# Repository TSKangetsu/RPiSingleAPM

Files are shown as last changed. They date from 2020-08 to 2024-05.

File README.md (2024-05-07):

# SingleFlight

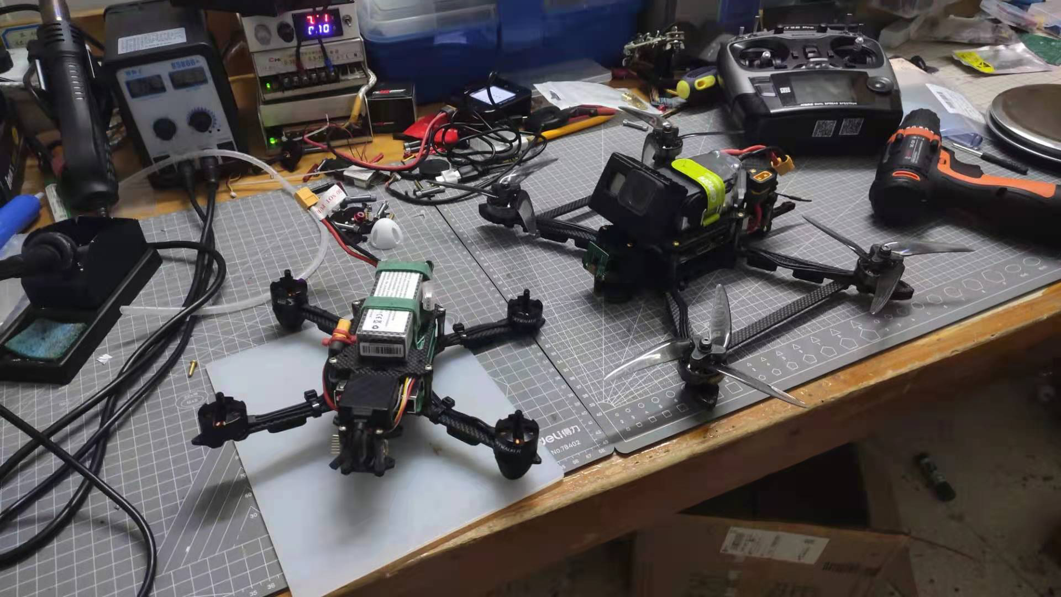
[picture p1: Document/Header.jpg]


SingleFlight is linux-userland C++ flight controller, without any external micro-controller

This project differs from Betaflight and inav in that it focuses on running controller in ARM-Linux, and suit for indoor navigation. <br/>

Warnning: This project is GPL3.0! <br/>

addon: when will it release first version? after GPS hold has done, should comming soon

## TODO: NOW trying support rockpi4b, openwrt onborad version will comming soon

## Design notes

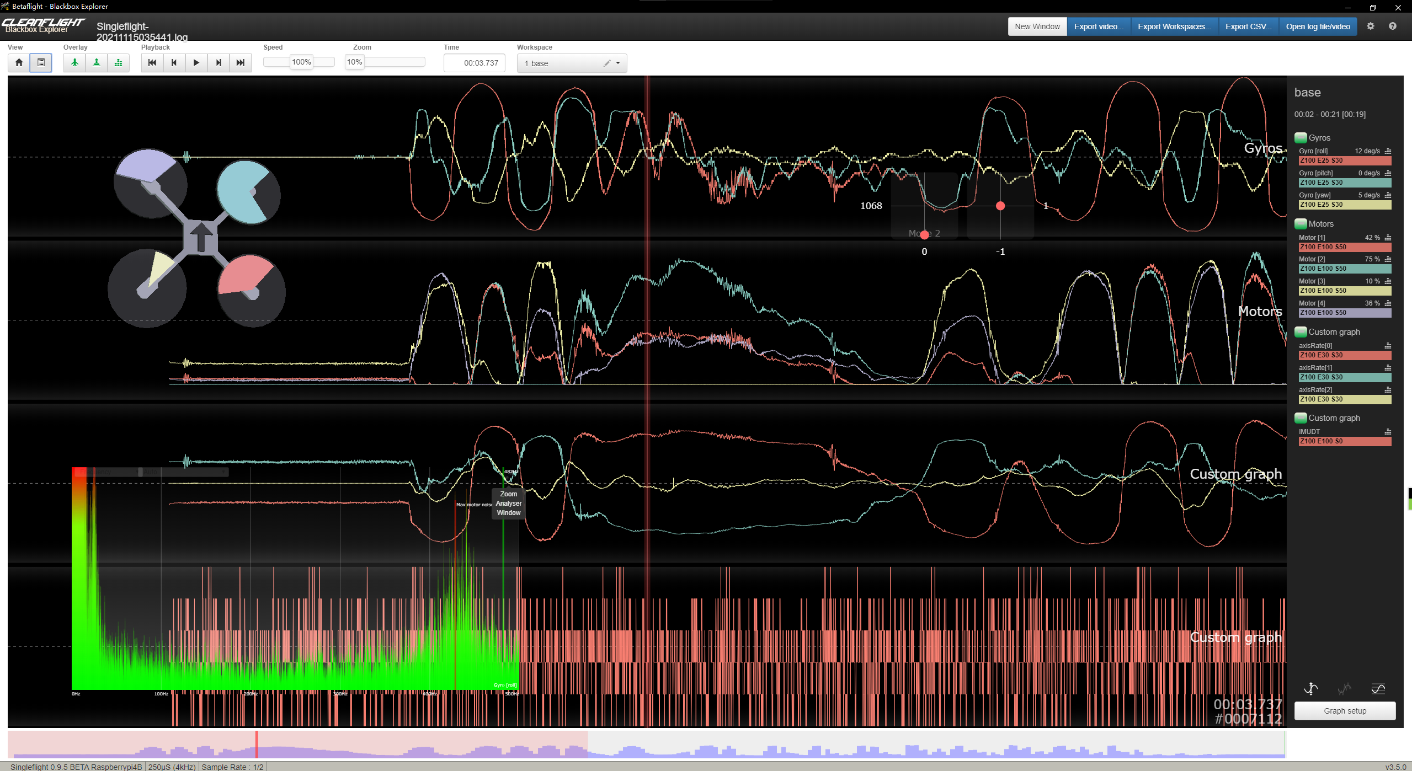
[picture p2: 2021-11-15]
Document/image.png

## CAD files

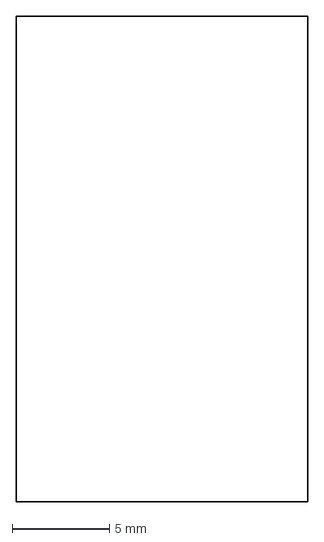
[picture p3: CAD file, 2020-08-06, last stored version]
PCB-pi/mpu9250.DXF
15.0 x 25.0 mm

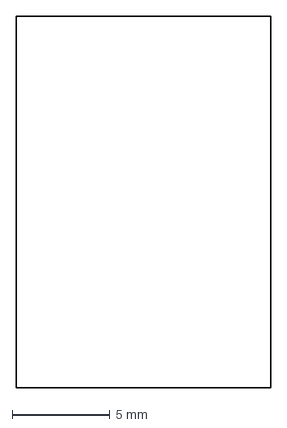
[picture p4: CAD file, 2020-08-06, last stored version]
PCB-pi/ms5611.DXF
13.0 x 19.0 mm

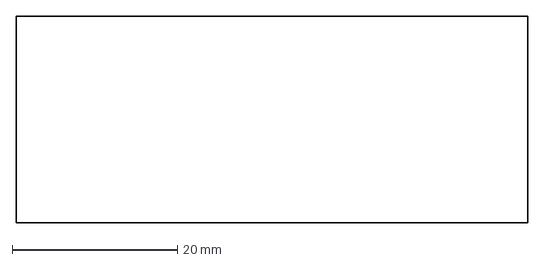
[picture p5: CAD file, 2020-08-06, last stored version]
PCB-pi/pca9685.DXF
62.0 x 25.0 mm

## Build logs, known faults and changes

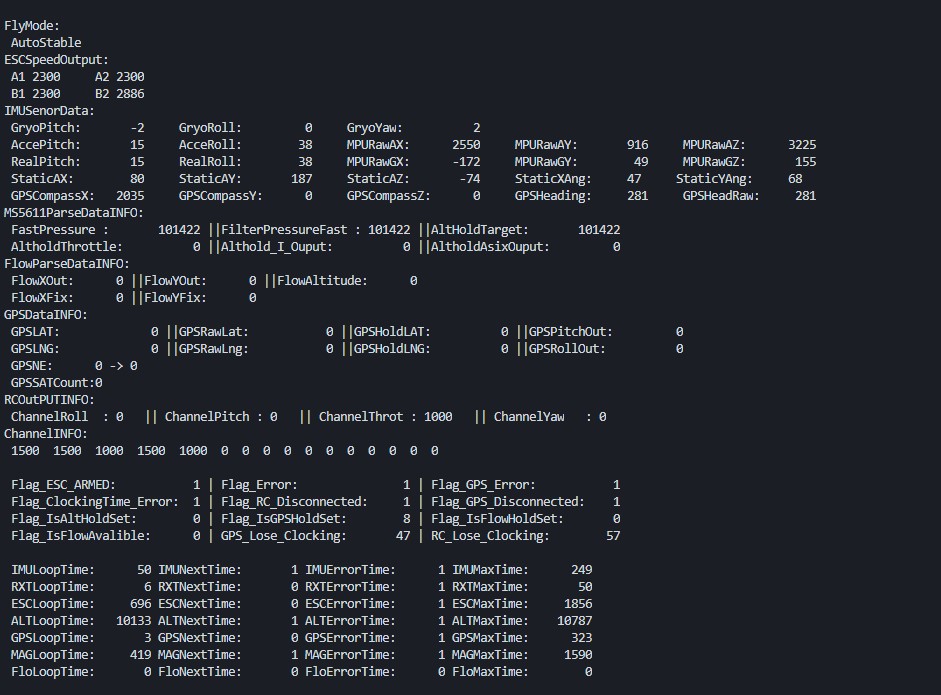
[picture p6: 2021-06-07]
Document/DebugInfo.jpg

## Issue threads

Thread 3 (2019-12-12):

Add MS5611 to support Althold Mode

TSKangetsu, 2019-12-12:

TSKangetsu, 2020-07-15:
alt fix should be add at  RF._uORB_RC_Out_Throttle , In progress

TSKangetsu, 2020-09-18:
Need test, on 9/20

TSKangetsu, 2020-10-27:
increase althold rate fresh from 50hz to 100hz

TSKangetsu, 2020-10-28:
at 100hz althold works well , testing pass

TSKangetsu, 2020-10-30:
hover throttle unstable need to fix

TSKangetsu, 2020-10-31:
may need accel to get climbeRate , bug accel data can't trusted

TSKangetsu, 2020-10-31:
4s throttle and 3s throttle are different , I meet some throuble

TSKangetsu, 2020-11-03:
can't use ms5611 to caculate hover throttle,should input hover throttle by manual

TSKangetsu, 2021-02-05:
will use vertical speed pid , this thread also at
https://github.com/TSKangetsu/RPiSingleAPM/issues/46

Closed 2021-04-05.

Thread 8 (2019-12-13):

FailedSafe landing support

TSKangetsu, 2019-12-13:

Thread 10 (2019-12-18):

improve timming clock detect

TSKangetsu, 2019-12-18:
Do not use timer out side , include timer at safycheck()

TSKangetsu, 2020-09-26:
SPI on new raspbain went error , with unstable latency
with https://github.com/raspberrypi/linux/issues/2094

solve: core_freq=250 (force_turbo=1) still on investigating

TSKangetsu, 2020-09-26:
and core_freq=250 to /boot/config.txt can solve , add to readme

TSKangetsu, 2021-02-04:
spi speed was up to 1mb/s , problem could not refound, closed

TSKangetsu, 2021-08-02:
this is a hardware issues because of the low voltage to raspberrypi

TSKangetsu, 2021-08-03:
dt is error with a little big delay , when fresh rate over 2khz, madgwick error become to big

TSKangetsu, 2021-08-04:
check here
https://stackoverflow.com/questions/54620641/why-nanosleep-adds-a-constant-delay-and-how-can-i-avoid-that
slove by time-50us

TSKangetsu, 2021-12-15:
https://github.com/TSKangetsu/RPiSingleAPM/commit/1f509caf203f00de5ce3eb194611f432136c3439

getimeofday is depend on systime but system clock, network time update cause some random issues, real dangerous

Closed 2021-12-15.

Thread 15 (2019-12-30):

Ibus Bug fix

TSKangetsu, 2019-12-30:
remove wiringPiSerial , using terminos

Closed 2019-12-31.

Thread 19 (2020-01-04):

Crashing on Raspberry3B+

TSKangetsu, 2020-01-04:
It seem like a time delay error

TSKangetsu, 2020-01-06:
control read time too long , delay error

TSKangetsu, 2020-01-06:
problem found: unsigned int force to int cost some problem , will fix up next version

Closed 2020-01-06.

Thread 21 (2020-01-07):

improve gryo filter

TSKangetsu, 2020-01-07:

TSKangetsu, 2021-05-12:
plan to use pt1? or biquad filter ,or dynamic

TSKangetsu, 2021-06-03:
current gryo filter is stable enough at  5'' to 7'' quad , close it temporary

Closed 2021-06-03.

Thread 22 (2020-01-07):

add kalman filter

TSKangetsu, 2020-01-07:
add at develop , but could test

TSKangetsu, 2020-10-15:
kalman filter is not to be used, do not works well

TSKangetsu, 2021-03-17:
kaman was add to 6219fcba6c9ecfa01a249ae43ae32336d2badb27
thanks https://github.com/simondlevy/TinyEKF/

TSKangetsu, 2021-04-05:
TinyEKF was used  in  navigation now

Closed 2021-04-05.

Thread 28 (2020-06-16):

Sensor Data correct checking System add

TSKangetsu, 2020-06-16:
check the sensor is working correct

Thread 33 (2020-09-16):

Task system add

TSKangetsu, 2020-09-16:
add task system for prevent gyro error

Closed 2020-09-26.

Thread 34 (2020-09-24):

Raspberrypi4 more 4 uart support

TSKangetsu, 2020-09-24:

TSKangetsu, 2020-09-24:
Raspberrypi4 has more uart port:
uart0   14  15              8   10
uart1   14  15              8   10
uart2   0   1   2   3       27  28  (I2C)
uart3   4   5   6   7       7   29
uart4   8   9   10  11      24  23  (SPI0)
uart5   12  13  14  15      32  33  (gpio-fan)

uart 1,3,5 will be using for pmw3901 and gps

TSKangetsu, 2020-09-24:
Redesigned PCB extend board:

TSKangetsu, 2020-09-24:
move pcb board i2c-0 to i2c-1 for uart2 , SDA0 , SCL0 is use for uart, i2c sensor go from sda1 and scl1

Closed 2021-11-11.

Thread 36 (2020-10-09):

Compass support

TSKangetsu, 2020-10-09:

TSKangetsu, 2020-10-09:
support MPU9250 compass and M8N compass

TSKangetsu, 2020-10-11:
用中文吐槽：
    根本搞不定，I2C状态的mpu9250还好说，把mpu9250作为主机读取9250的磁力计太过恶心，响应极慢，状态完全不可知，可能会抛弃spi模式的mpu9250板载磁力计

TSKangetsu, 2020-10-12:
在 https://github.com/TSKangetsu/RPiSingleAPM/commit/e544b20a4bf567b559938b5c271917177a4f9de5 中解决

TSKangetsu, 2020-11-06:
mpu9250的电子罗盘在gpio5V供电时几乎不可用，将优先对gps罗盘提供支持

TSKangetsu, 2020-11-12:
QMC5883L support complete

TSKangetsu, 2021-11-18:
compass now support base angle asix , it works fine, but i want to use AHRS.....

TSKangetsu, 2021-11-19:
AHRS support complete,

Now ignore compass input AHRS when mag is being influence by eletronic

TSKangetsu, 2021-12-20:
should support HMC5883

TSKangetsu, 2021-12-20:
HMC5883L is great! very stable and correct ,fuck QMC5883, everytime QMC5883 boot must calibrated

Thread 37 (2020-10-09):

GPS M8N Support

TSKangetsu, 2020-10-09:

TSKangetsu, 2020-11-08:
gps reading terrible delay over 6s , debuging

TSKangetsu, 2020-11-08:
这并不是一个延迟的问题，而是gps输出没有给进pid闭环导致pid与gps对抗

TSKangetsu, 2020-11-12:
GPS angle caculate error fixed

https://github.com/TSKangetsu/RPiSingleAPM/commit/5803b03a980b3fd887e40f29bbde1c3bb217cbd5

TSKangetsu, 2020-11-20:
GPS delay time is depending when serial port is being opened, if serial port is opened and free for 5sec , the data time line also  delay 5sec  , WTF???
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

TSKangetsu, 2021-11-08:
this plan is pushing for a long time...
wait for the GPS kit and will develop soon...

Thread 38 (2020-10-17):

Using fixed pwm value instead of rc pwm

TSKangetsu, 2020-10-17:

Closed 2024-05-07.

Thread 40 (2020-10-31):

New Loging System add

TSKangetsu, 2020-10-31:
log pid output ,accel gryo ,altitude info for survey

TSKangetsu, 2021-08-16:
same to
https://github.com/TSKangetsu/RPiSingleAPM/issues/60

close

Closed 2021-08-16.

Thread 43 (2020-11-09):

roll pitch throttle fixed up

TSKangetsu, 2020-11-09:

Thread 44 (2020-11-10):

Unexpected Accel data ouput

TSKangetsu, 2020-11-10:

TSKangetsu, 2020-11-10:
this bug also cause compass error
https://github.com/TSKangetsu/RPiSingleAPM/issues/36

TSKangetsu, 2020-11-10:
it seems to be a hardware problem , try to add accel xyz calibration

TSKangetsu, 2020-11-10:
the testing quadcopter's mpu accel z output is 2100 away from center , this is an hardware error

TSKangetsu, 2020-11-11:
add accel calibration at https://github.com/TSKangetsu/RPiSingleAPM/commit/472f2326f5d2c099a423c9d3b051ebbac80c45c1

using SingleAPM -a to calibrate accel

Closed 2020-11-11.

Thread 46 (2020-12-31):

Accel movement detection

TSKangetsu, 2020-12-31:

TSKangetsu, 2021-02-04:
was done at https://github.com/TSKangetsu/RaspberryPiMPU/commit/2f9b78fb7e9962127a78856a36eaf97fbc136a7f

TSKangetsu, 2021-04-05:
now ,it fully support with 10hz flow and accel movement detection, configuration!!!!!

TSKangetsu, 2021-05-04:
accel on z with pressure is unstable , try using Accel PID controller instead Speed control,
Posistion * P -> Speed * P2 -> Accel * PID

TSKangetsu, 2021-05-09:
accel work able now , but easy to influence cause by vibration

TSKangetsu, 2021-05-09:
plan to add vibration detect dynamic change accel beta? I don't kown.....  just try

TSKangetsu, 2021-05-09:
same issues like this
https://github.com/iNavFlight/inav/issues/486

TSKangetsu, 2021-05-12:
using 5hz throttle LPF make baro altitude hold is stable now
switch to horizontal movement detect

TSKangetsu, 2021-05-12:
althold problem is not cause by accel vibration,  barometer is bumping , so throttle is keep little move, 5hz sulove perfect

TSKangetsu, 2021-05-26:
vibration detect support

TSKangetsu, 2021-06-11:
imu attitude convert accel became terriaful when accel trust gain higher

TSKangetsu, 2021-06-12:
rotation matrix base accel deal support now , just need a stable attitude feedback

TSKangetsu, 2021-08-13:
Because of the vibration , even on ground disarm , speed reference also change crazy , still found some way to deal

TSKangetsu, 2021-08-14:
biqaud  lpf at low sample rate won't work well, Sample rate at lease >500hz ,

TSKangetsu, 2021-08-14:
mpu6000 DLPF's Gyro and accel is bound, but mpu9250 are separated, so directly set 44hz hardware lpf for mpu9250 is well?..
still need test

TSKangetsu, 2021-08-14:
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

TSKangetsu, 2021-08-14:
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

TSKangetsu, 2022-10-26:
now I know: INAV is using Speed-base PID controller , NOT ACCELRATION-BASE, should fallback navigation PID to Speed

TSKangetsu, 2022-10-26:
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

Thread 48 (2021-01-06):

GRYO: pitch and roll is not correct when yaw change

TSKangetsu, 2021-01-06:

TSKangetsu, 2021-01-06:
fix at Master https://github.com/TSKangetsu/RPiSingleAPM/commit/70311a7940c91641bba5ec6a41bac298fa3beb66
and
ad dev  https://github.com/TSKangetsu/RPiSingleAPM/commit/66b56c99425fcdebfa19f5bab78698124eaafdec

Closed 2021-01-06.

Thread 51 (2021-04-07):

Position hold Brake support

TSKangetsu, 2021-04-07:

TSKangetsu, 2021-06-09:
Speed braking seen not right when copter fast bark, will cause flow output unstable

TSKangetsu, 2021-06-09:
flow move output also not seems well when only x or only y change , will cause other movement

TSKangetsu, 2021-06-09:
like a imu accel problem
https://github.com/TSKangetsu/RPiSingleAPM/issues/68

Closed 2021-06-12.

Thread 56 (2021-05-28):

Unstable yaw controller

TSKangetsu, 2021-05-28:

TSKangetsu, 2021-05-28:
PID Yaw's controller problem ,fast span will cause pitch and roll jumping , may a  mixer  problem

TSKangetsu, 2021-05-29:
this is not a mixer problem, mixer is correct , Yaw PID's I logic should be reconsider

TSKangetsu, 2021-05-29:
a health and strong PID settings can prevent fast Yaw change cause pitch and roll I-Gain jump

TSKangetsu, 2021-05-29:
INAV seems to take a lot limit on I-Term controller , this issues may delay

TSKangetsu, 2021-05-29:
This issues will move to
https://github.com/TSKangetsu/RPiSingleAPM/issues/58

TSKangetsu, 2021-05-30:
this not a I gain Problem , even the I gain is zero , quad still jumping

TSKangetsu, 2021-05-31:
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
this is a mixer to caculate problem?

TSKangetsu, 2021-05-31:
mixer output was block at 2600? Unkown problems

TSKangetsu, 2021-06-01:
This issues is cause by over throttle cutoff asix，now fix

Closed 2021-06-01.

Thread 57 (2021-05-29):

Better I Term and D Term filter add

TSKangetsu, 2021-05-29:

TSKangetsu, 2021-06-02:
same to
https://github.com/TSKangetsu/RPiSingleAPM/issues/57

TSKangetsu, 2021-06-02:
double D gain filter is require

Closed 2021-06-04.

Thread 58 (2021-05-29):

Better I-Term controller

TSKangetsu, 2021-05-29:

TSKangetsu, 2021-05-29:
inav is using two tips to limit PID-I output,
1.motor mixer feedback I gain to slow down I value up
2.If motor Mixer is over throttle , set the limit when I value is reach the line

Closed 2021-06-02.

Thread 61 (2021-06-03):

Althold problems when re-arm

TSKangetsu, 2021-06-03:
when althold langding and arm , and then re-enable althold , copter will drop

TSKangetsu, 2021-06-03:
This issues may cause by accel asix math problem

TSKangetsu, 2021-06-04:
cause by  sqrt -1 in mpudata

Closed 2021-06-04.

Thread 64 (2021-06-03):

Gryo Temperature fix and high DPS support

TSKangetsu, 2021-06-03:

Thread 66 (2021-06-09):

Dynamic position Hold pid support

TSKangetsu, 2021-06-09:

TSKangetsu, 2021-06-09:
like a imu accel problem
https://github.com/TSKangetsu/RPiSingleAPM/issues/68

Closed 2021-06-09.

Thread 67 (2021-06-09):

flow position control problem

TSKangetsu, 2021-06-09:

TSKangetsu, 2021-06-09:
like a imu accel problem
https://github.com/TSKangetsu/RPiSingleAPM/issues/68

Closed 2021-06-12.

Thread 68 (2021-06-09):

IMU accel Convert unstable

TSKangetsu, 2021-06-09:

TSKangetsu, 2021-06-09:
cause by https://github.com/TSKangetsu/RPiSingleAPM/issues/69

TSKangetsu, 2021-06-09:
导致惯导不稳定的主要因素：
1.陀螺仪姿态不够准确
2.姿态补偿加速度算法存在较大问题

Closed 2021-06-12.

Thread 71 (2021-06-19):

addon notch filter require

TSKangetsu, 2021-06-19:
5inch copter will have some unexpected vibration at 100hz, when gryo total filter is 250hz , should deal with notch filter

TSKangetsu, 2021-06-20:
Don't use double notch, will cause a lot delay.
Single one works very well

TSKangetsu, 2021-06-20:
will support dynamic notch in times

Closed 2021-07-20.

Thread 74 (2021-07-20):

hardware lpf question

TSKangetsu, 2021-07-20:

TSKangetsu, 2021-07-25:
In fact, MPU module is set to 42hz hardware lpf and output speed only 1000khz, and using any clean flight filter is useless , and 42hz lpf cause a very high delay, and require a horrible high d gain

TSKangetsu, 2021-07-25:
now i set correctly with 250hz lpf ，7 inch copter fly horrible stable.

TSKangetsu, 2021-07-25:
also notice the accel hardware lpf , should not be too low

Closed 2021-07-25.

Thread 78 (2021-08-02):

raspberry pi low voltage issues

TSKangetsu, 2021-08-02:
low voltage cause tons of problem should be high notice

TSKangetsu, 2021-08-02:
same to this issues https://github.com/TSKangetsu/RPiSingleAPM/issues/10

TSKangetsu, 2021-08-02:
low voltage will cause i2c horrible unstable, SPI Clock also influence , this is most important infomation

TSKangetsu, 2021-08-02:
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
 stable 5.0v voltage error times

TSKangetsu, 2021-08-02:
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
unstable at 4.7v , error clocking horribly increase

TSKangetsu, 2021-08-02:
those result is using DMA SPI access , if in SPIDEV with userland , this will terrible

Closed 2021-08-03.

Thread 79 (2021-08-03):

Gyro temp drift improve

TSKangetsu, 2021-08-03:

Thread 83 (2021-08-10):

ALTHOLD air cushion effect detect

TSKangetsu, 2021-08-10:
using baro ground timeout and sonar

TSKangetsu, 2021-08-10:
7inch have huge air cushion influence, after take off will cause -50cm/s speed change

Closed 2021-08-13.

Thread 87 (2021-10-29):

General Linux driver support

TSKangetsu, 2021-10-29:
In Order to support Radxa or RK3399 and some arm borad

TSKangetsu, 2021-10-31:
spi has a lot driver problem in linux,
will using libmraa?

TSKangetsu, 2021-11-07:
Libmraa: meanless.

there still spidev inside ,why don't i just using spidev and  suit for driver DMA?😒

TSKangetsu, 2021-11-08:
Done

Closed 2021-11-08.

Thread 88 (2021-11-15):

Unexpected motor output

TSKangetsu, 2021-11-15:
prossibly casue by new pca9685 driver

TSKangetsu, 2021-11-15:
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
seems not a driver's bug

TSKangetsu, 2021-11-15:
this issue is cause by dt' problem
https://github.com/TSKangetsu/RPiSingleAPM/issues/89

Closed 2021-11-15.

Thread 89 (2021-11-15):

DT cause PID and motor output error

TSKangetsu, 2021-11-15:

TSKangetsu, 2021-11-15:
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

it seems to be DT cause randor error, when drop down to 2KHZ , it works fine, but 3khz or 4khz have a lot random unexpect output

TSKangetsu, 2021-11-15:
fix with dt sleep when dt overclock cause pid unexpected output
notice this because loop freq may drop a lot
https://github.com/TSKangetsu/RPiSingleAPM/commit/06b8e11d0a2dfbd81750aa7725137540e7e81584

TSKangetsu, 2021-11-15:
ok , i think i found the true reason
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

TSKangetsu, 2021-11-19:
move to https://github.com/TSKangetsu/RPiSingleAPM/issues/90

Closed 2021-11-19.

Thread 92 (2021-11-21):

Improve sensor for XY invert

TSKangetsu, 2021-11-21:

Closed 2021-12-03.

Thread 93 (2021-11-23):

Rebound pitch problem

TSKangetsu, 2021-11-23:
for comvince , after added mpu flip function, Pitch is revert from "move forward -" to "move forward +"

https://github.com/TSKangetsu/RPiSingleAPM/commit/4ec5ec44419bf4c3821a98b6d08af04de410d102

Closed 2023-08-27.

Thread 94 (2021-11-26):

gyro filter unexpected output

TSKangetsu, 2021-11-26:

TSKangetsu, 2021-11-26:
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

after fliter event noiser than gyro raw data???

TSKangetsu, 2021-11-26:
cause by dynamic gyro notch

Closed 2021-11-26.

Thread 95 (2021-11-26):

dynamic gyro improve

TSKangetsu, 2021-11-26:

TSKangetsu, 2021-11-26:
point to

https://github.com/TSKangetsu/RPiSingleAPM/issues/94

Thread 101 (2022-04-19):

strange behavior with 64bit raspbain

TSKangetsu, 2022-04-19:
pigpio radom output , magwick caculate , too weired

TSKangetsu, 2022-04-19:
In fact, this problem not appear in rockpi4, they all aarch64, this is a raspbian only problem

TSKangetsu, 2022-04-19:
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

TSKangetsu, 2022-04-19:
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

seems rockpi's aarch64 compiler's long is 32bit

not a raspbain problem

TSKangetsu, 2022-04-19:
pigpio still with some problem

TSKangetsu, 2022-04-19:
invertsqrt bit problem also fix  pigpio issues, propelly mmap overflow

TSKangetsu, 2022-04-19:
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

don't turbo gpu&cpu when using pigpio on 64bit raspbian

https://github.com/joan2937/pigpio/issues/372

TSKangetsu, 2022-04-19:
cpu freq 1500 may make issues on 64bit ,need to notice

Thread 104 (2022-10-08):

support CRSF for ELRS, improve reciver logic

TSKangetsu, 2022-10-08:
supporting ELRS, and consider connect esp32 reciver as usb connection

support RC failedsafe if throttle low condition

rebuild rc as caculate rc framerate

TSKangetsu, 2023-10-21:
telemetry supported

Closed 2024-05-07.

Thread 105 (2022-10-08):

Motor unkown reason twitch a litte

TSKangetsu, 2022-10-08:

TSKangetsu, 2022-10-08:
possiblty because oneshot over 400HZ, on wire rising time over flow cause twitch,
this may a hardware issues

Closed 2022-10-10.

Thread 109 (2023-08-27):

unkown behavior for rockpi4b when mpu reading accel

TSKangetsu, 2023-08-27:
only read from 0x3A (one bit before 0x3B) can work

TSKangetsu, 2023-09-01:
mpu voltage 5v, over press, now fix pcb

Closed 2023-09-01.

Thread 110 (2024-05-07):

new INU gyro ICM support

TSKangetsu, 2024-05-07:
invensense icm20602 icm40609 support

TSKangetsu, 2024-06-11:
https://github.com/TSKangetsu/RaspberryPiMPU/commit/6dc29a63936f2609e6ff4c31d6b0cf4384bb5613

Closed 2024-06-11.

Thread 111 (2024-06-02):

fix wing support

TSKangetsu, 2024-06-02:

TSKangetsu, 2024-06-02:
link to this https://github.com/TSKangetsu/RPiSingleAPM/issues/103

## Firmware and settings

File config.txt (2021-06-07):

# This is a example config for Raspberrypi4B
framebuffer_width=640
framebuffer_height=380
enable_tvout=1
sdtv_mode=0
sdtv_aspect=3
arm_freq=1500
force_turbo=1
core_freq=360
core_freq_min=360
dtparam=audio=on
[pi4]
max_framebuffers=3
dtparam=i2c_arm=on
dtparam=i2c_baudrate=800000
dtparam=spi=on
gpu_mem=128
dtoverlay=pi3-miniuart-bt
dtoverlay=uart3
dtoverlay=uart5
[all]
start_x=1
enable_uart=1

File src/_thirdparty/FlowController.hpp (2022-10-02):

#pragma once
#include <chrono>
#include <thread>
#include <time.h>
#include <unistd.h>
#include <functional>
#include <sys/time.h>
#include <condition_variable>
#define LINUX_SYSTEM_SLEEP_DELAY 100

class FlowThread : public std::thread
{
public:
    inline FlowThread(std::function<void()> thread, int CPUID, float ClockingHZ);

    inline FlowThread(std::function<void()> thread) : FlowThread(thread, -1, -1){};
    inline FlowThread(std::function<void()> thread, int CPUID) : FlowThread(thread, CPUID, -1){};
    inline FlowThread(std::function<void()> thread, float ClockingHZ) : FlowThread(thread, -1, ClockingHZ){};

    inline void FlowTryStop();
    inline void FlowStopAndWait();
    inline void FlowWait() { this->join(); };

    float RunClockHz = 0;
    uint32_t TimeOut_MAX = 0;
    uint32_t TimeDT = 0;

private:
    uint32_t GetTimeStamp()
    {
        struct timespec tv;
        clock_gettime(CLOCK_MONOTONIC, &tv);
        return ((tv.tv_sec * (uint32_t)1000000 + (tv.tv_nsec / 1000)));
    }

    uint32_t TimeThreadStart = 0;
    uint32_t Time__Max = 1000000; // defaultly run 1HZ
    uint32_t TimeStart = 0;
    uint32_t Time__End = 0;
    uint32_t Time_Next = 0;
    uint32_t ThreadSpend = 0;
    uint32_t SleepOffset = 100;

    float tmpClock = 0;
    float targetClock = 0;
    int clockcount = 1;

    bool lockFlag = false;

    std::mutex copylock;
    std::condition_variable notifyWait;

    bool IsThreadRunning = false;
    std::function<void()> threadMain = [] {};
};

FlowThread::FlowThread(std::function<void()> thread, int CPUID, float ClockingHZ)
    : std::thread(
          [&]
          {
              sleep(1);
              IsThreadRunning = true;
              //
              std::unique_lock<std::mutex> lockWait{copylock};
              while (!lockFlag)
                  notifyWait.wait(lockWait);
              //
              TimeThreadStart = GetTimeStamp();
              while (IsThreadRunning)
              {
                  TimeStart = GetTimeStamp() - TimeThreadStart;
                  Time_Next = TimeStart - Time__End;
                  //
                  threadMain();
                  //
                  Time__End = GetTimeStamp() - TimeThreadStart;
                  ThreadSpend = Time__End - TimeStart;
                  //
                  if (Time__Max > 0)
                  {
                      if (ThreadSpend + Time_Next + SleepOffset > Time__Max | Time_Next < 0)
                      {
                          usleep(1);
                      }
                      else
                      {
                          usleep(Time__Max - ThreadSpend - Time_Next - SleepOffset);
                      }
                      if (ThreadSpend + Time_Next > TimeOut_MAX)
                      {
                          TimeOut_MAX = ThreadSpend;
                      }
                      //
                      if (clockcount > targetClock)
                      {
                          RunClockHz = (1.f / (tmpClock / (float)clockcount) * 1000000.f);
                          clockcount = 0;
                          tmpClock = 0;
                      }
                      tmpClock += TimeDT;
                      clockcount++;
                  }
                  Time__End = GetTimeStamp() - TimeThreadStart;
                  TimeDT = Time__End - TimeStart;
              }
          })
{
    threadMain = thread;
    //
    targetClock = ClockingHZ;
    Time__Max = ClockingHZ > 0.0 ? ((int)((1.f / ClockingHZ) * 1000000.f)) : 0;
    //
    if (CPUID >= 0)
    {
        cpu_set_t cpuset;
        CPU_ZERO(&cpuset);
        CPU_SET(CPUID, &cpuset);
        int rc = pthread_setaffinity_np(this->native_handle(), sizeof(cpu_set_t), &cpuset);
    }
    //
    {
        std::unique_lock<std::mutex> lockWaitMain{copylock};
        lockFlag = true;
    }
    notifyWait.notify_all();
};

void FlowThread::FlowTryStop()
{
    IsThreadRunning = false;
};

void FlowThread::FlowStopAndWait()
{
    FlowTryStop();
    if (this->joinable())
        this->join();
};

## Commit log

2019-10-31 pwm level test add
2019-11-01 pid add (tmp
2019-11-04 Roll fix (none test
    [SingleAPM.hpp]
2019-11-18 Pitch and roll accel base detect add
2019-11-19 gryo sensors calibration add
2019-11-22 sensorData fix and Gryo Accel mix work well
    [SingleAPM.cpp, SingleAPM.hpp]
2019-11-25 throttle to PCA9685 add
2019-11-25 P to motor add
2019-11-26 control calibration and pid_all add
2019-11-26 I max cacu add, var name fix,accel cali add
    [SingleAPM.cpp, SingleAPM.hpp]
2019-11-26 var name fix (tmp
    [SingleAPM.cpp, SingleAPM.hpp]
2019-11-26 failed safe bug fix
    [SingleAPM.hpp]
2019-11-27 motor speed bug fix
    [SingleAPM.cpp, SingleAPM.hpp]
2019-11-29 cpu bind thread add
2019-11-29 esc calibration add ,bug fix
    [SingleAPM.cpp, SingleAPM.hpp]
2019-11-29 lot bug fix , SPI 9250 support
    [SingleAPM.cpp, SingleAPM.hpp]
2019-11-30 bug fix , control output down
    [SingleAPM.cpp, SingleAPM.hpp]
2019-12-03 sensorsParse func fix
2019-12-03 SensorParse improve
2019-12-04 unable to fix spi write (tmp ,help!
    [SingleAPM.hpp]
2019-12-05 auto leveling works , RC bug fix
    [SingleAPM.hpp]
2019-12-05 Pitch roll yall pid devlied ,not test
2019-12-06 SPI write bug fix
    [SingleAPM.cpp, SingleAPM.hpp]
2019-12-06 PID ID temp fixup
    [SingleAPM.hpp]
2019-12-07 accel calibration add (tmp
2019-12-10 danger change change yall to yaw MS5611 change control input args add Accel X Y fix to Accel Roll Pitch
    [SingleAPM.hpp]
2019-12-11 accel cali fix up (Tmp
    [SingleAPM.hpp]
2019-12-11 IBUS fix , control improve
    [SingleAPM.hpp]
2019-12-12 RC improve cali fix up Control max out improve
    [SingleAPM.hpp]
2019-12-12 control start up protect improve rc safe switch add
2019-12-12 APMconfig fix start up protect improve
    [SingleAPM.hpp]
2019-12-12 large improve esc speed func improve sbus converter check improve
2019-12-12 sbus converter rc check fix
    [SingleAPM.hpp]
2019-12-12 danger change var move device check failedsafe add ms5611 remove
    [SingleAPM.hpp]
2019-12-18 set RaspberryPi_SBUS as submodule
2019-12-23 switch to more channel (untest
2019-12-23 improve fix var name json fix
    [SingleAPM.cpp, SingleAPM.hpp]
2019-12-23 sbus , ibus bug fix
    [SingleAPM.cpp, SingleAPM.hpp]
2019-12-23 100 commit congraduate Gryo cali bug fix
    [SingleAPM.hpp]
2019-12-26 control error detect add
    [SingleAPM.cpp, SingleAPM.hpp]
2019-12-30 Gyro filter add IIR filter Info: filtertype = Butterworth, passtype = Lowpass, order = 5, samplerate = 250, corner1 = 70; made by http://www-users.cs.york.ac.uk/~fisher/mkfilter/
2019-12-30 arm unlock bug fix down accel
    [SingleAPM.hpp]
2019-12-31 configsetter fix mpu and rc type improve
    [SingleAPM.cpp, SingleAPM.hpp]
2019-12-31 alt fix full (untest
    [SingleAPM.hpp]
2020-01-06 pressure add (tmp
2020-01-07 filter was set to 50hz , 2 order
2020-01-11 MS5611 read pass , filter need to fix
    [SingleAPM.cpp, SingleAPM.hpp]
2020-01-13 accel filter nopass remove
2020-01-13 reserv add and fix
    [SingleAPM.hpp]
2020-03-15 filter improve
2020-03-17 mix Filter improve
2020-04-01 kalman filter (need redesign ,don't use)
    [SingleAPM.cpp, SingleAPM.hpp]
2020-04-11 useable kalman-filter add ( could not test
2020-07-19 @SaftyChecking() DISARMED Logic error Fix UP @Clocking Time Error show Add @Time Clock improve
    [SingleAPM.cpp, SingleAPM.hpp]
2020-07-21 MS5611 pressure and alt show add
2020-08-02 raspberrySensor borad pcbDoc add
    [SensorCrack.PcbDoc]
2020-08-13 pcb clear
    [DRIVER-PCA9685PW_TSSOP28_.PcbLib, DRIVER-PCA9685PW_TSSOP28_.SchLib, MPU-9250.PcbLib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]
2020-08-24 switch format from vs2019 to vscode
2020-09-14 micros clocking tmp fix (eme
    [SingleAPM.cpp, SingleAPM.hpp]
2020-09-17 Task dev finsh , task time need to fix
    [SingleAPM.cpp, SingleAPM.hpp]
2020-09-17 task improve still fixing
    [SingleAPM.cpp, SingleAPM.hpp]
2020-09-18 move alttitudeTask after Imu
2020-09-30 MS5611 filter add
2020-09-30 pressure add to filter
2020-10-08 flymode add rc fix (tmp
    [SingleAPM.cpp, SingleAPM.hpp]
2020-10-08 ms5611 turn to cm as alt leveling throttle need to test
2020-10-09 SPI config fix mag add whoami test (tmp
    [SingleAPM.cpp, SingleAPM.hpp]
2020-10-11 mpu9250 mag remote , won't fix ,need help
    [SingleAPM.cpp]
2020-10-12 int pin cfg solve AK8963 problem ,still on survey
    [SingleAPM.cpp]
2020-10-12 CP:spi mpu9250 ak8963 slave test final pass
2020-10-16 alt base value bug fix
    [SingleAPM.cpp, SingleAPM.hpp]
2020-10-16 ms5611 filter improve
2020-10-17 autopilot mode switch add , althold improve
2020-10-17 rc error roll back and flymode bug fix
    [SingleAPM.cpp]
2020-10-18 althold pid comfirm APMConfig althold pid add
2020-10-18 althold max bug fix
    [SingleAPM.cpp, SingleAPM.hpp]
2020-10-19 althold logic and bug fix
    [SingleAPM.cpp, SingleAPM.hpp]
2020-10-22 fast recomfirm,ms5611 filter improve
2020-10-23 switch thread loop speed , positionTask add
2020-10-23 smooth gps 50hz sim add
2020-10-24 GPS position hold pid add
2020-10-26 esc limit add ESC calibrator add Init Check add
2020-10-27 Althold 100hz support compass header useable
2020-10-28 gryo filter 1000hz
2020-10-28 althold I gain fix
    [SingleAPM.cpp]
2020-11-01 improve pid implement
2020-11-03 Hover Throttle add
2020-11-04 althold 88hz clock set
2020-11-04 gryo and mag yaw add
2020-11-07 QMC5883L header add , compass calibration add
2020-11-08 GPS ouput throttle fixed into pid controller
    [SingleAPM.cpp, SingleAPM.hpp]
2020-11-08 clean gps bug check
    [SingleAPM.cpp]
2020-11-08 MPU MAG improve , calibration add
2020-11-09 movement throttle asix add
2020-11-10 Uart Device Config add
2020-11-11 Accel calibration add test comfirm
2020-11-12 gps compass angle issues fix up
    [SingleAPM.cpp, SingleAPM.hpp]
2020-11-12 fix up compass YX
    [SingleAPM.cpp]
2020-11-15 Merge branch 'NDTask_Ver' of https://github.com/TSKangetsu/RPiSingleAPM into NDTask_Ver
    source big fix up into src
    [SingleAPM.hpp, pca9685.c, pca9685.h]
2020-11-16 gps output pitch and roll revers , testing
    [SingleAPM.cpp]
2020-11-19 error time add , increase spi speed
    [SingleAPM.cpp, SingleAPM.hpp]
2020-11-19 eme: pwm fix
2020-11-20 GPS delay bug fix
    [SingleAPM.cpp]
2020-11-29 CP: GPS work correct version
    [SingleAPM.cpp, SingleAPM.hpp]
2020-12-02 GPS error fix sbus update DEBUG cleaner
    [SingleAPM.cpp, SingleAPM.hpp]
2020-12-05 Flow Device add test pass
2020-12-09 flow 100hz simlatuor add , RaspberrypiRC Update
2020-12-11 flow hold funciton add
2020-12-13 ms5611 data error fix
    [SingleAPM.cpp, SingleAPM.hpp]
2020-12-13 pressure convert float to double
2020-12-29 remove unused filter calibration rebuilding
2021-01-02 remove unusage pid function
2021-01-03 mpu fix ,ms5611 improve
    [SingleAPM.cpp, SingleAPM.hpp]
2021-01-06 yaw reverse
2021-01-06 EME:GRYO YAW for Pitch and Roll bad bug!!!! yaw rc reverse
    [SingleAPM.cpp]
2021-02-01 disable flow function
2021-02-18 ms5611 switch to climbe rate accel vertial speed to cm/s ,movement to cm accel and ms5611 drift simple filter update mpu module
    [SingleAPM.cpp, SingleAPM.hpp]
2021-02-28 flow surface altitude correction
    [SingleAPM.cpp, SingleAPM.hpp]
2021-03-13 sonar hold support
2021-03-18 pid target adjustment
2021-03-20 flow avaliable improve
2021-03-26 extend pid add accel movement improve althold is use able
2021-03-30 Flow angle asix test pass (tmp
2021-04-05 add a example for raspberrypi4b boot config
    [config.txt]
2021-04-06 startup protect fix auto takeoff untested
    [SingleAPM.cpp, SingleAPM.hpp]
2021-04-08 yaw reverse add gps change speed controller settings add flow quality safe add flow dt improve speedhold bug fix
    [SingleAPM.cpp, SingleAPM.hpp]
2021-04-08 eme: pos xy asix error fix
    [SingleAPM.cpp, SingleAPM.hpp]
2021-04-08 ARM controller user improve device setup flag use add
2021-04-09 fix flow out total nan error
    [SingleAPM.hpp]
2021-04-14 speed hold bug fix
    [SingleAPM.cpp]
2021-04-19 Servo controller add
2021-04-20 User auto Z speed fix
    [SingleAPM.cpp]
2021-04-22 auto takeoff eme bug fix
    [SingleAPM.cpp, SingleAPM.hpp]
2021-04-29 pressure altitude improve
2021-05-04 cp :: MS5611 improve , speed pid final
2021-05-05 accel pid not well testing
2021-05-08 accel althold controll tri pid compelete
2021-05-12 stable baro althold comfirm test pass :throttle LPF 5hz can works fine
2021-05-12 config improve ,device improve
2021-05-12 filter config improve but no implement MPU update
2021-05-13 when sonar usable disable baro
2021-05-13 all lpf implement gryo yaw lpf add
2021-05-19 update imu
2021-05-26 CP: YAW litmit logic fix (importan pos accel change ,unsupport fake rc no implement
    [SingleAPM.cpp, SingleAPM.hpp]
2021-05-29 old mixer yaw need a strong pid config
2021-06-02 PIDExtend bug fix ARSHDisable improve D controller Gryo only leveling controller throttle asix leveling dynamic I gain add
    [SingleAPM.cpp, SingleAPM.hpp]
2021-06-03 7inch pid config update double D filter add
2021-06-04 5inch pos pid update
2021-06-04 IMU mix Remove
2021-06-07 barking support pos improve pos pid update
2021-06-12 braking and flow gain config add
2021-06-21 RC filter bug fix
    [SingleAPM.cpp, SingleAPM.hpp]
2021-07-16 lazy throttle improve mpu update dynamic angle limit disable esc cali improve
2021-07-21 bug fix , mpu update
    [SingleAPM.cpp, SingleAPM.hpp]
2021-07-24 rate limit and lazy throttle config add
2021-07-25 navgation update move out of attitude new failedsafe is add not implement
    [SingleAPM.cpp, SingleAPM.hpp]
2021-07-26 mis match pt1filter bug pt1ap4 should not be use before init
    [SingleAPM.cpp, SingleAPM.hpp]
2021-07-26 GyroStage2 filter add
2021-07-27 TPA support not test (untested push deinit add not test old led remove
2021-07-28 thread sign add module update
2021-08-03 max 7inch pid tune update
2021-08-03 timestamp instead of micro MPU update: madgwick dt update improve madgwick accel weight bug fix imu dt time detect add spi data tmp improve
    [SingleAPM.cpp, SingleAPM.hpp]
2021-08-04 linux usleep() timer_stop bug fix
    [SingleAPM.cpp, SingleAPM.hpp]
2021-08-04 ESC now support oneshot125
2021-08-04 Failed safe improve RateHold implement
    [SingleAPM.cpp, SingleAPM.hpp]
2021-08-05 navigation drop to 250hz mpu update
2021-08-06 althold stick safe bug fix nav 250hz update from mpu
    [SingleAPM.cpp, SingleAPM.hpp]
2021-08-07 PID now not influence by pid loop time
2021-08-07 attitude pid filter dt fix
    [SingleAPM.cpp]
2021-08-09 mpu online calibrate support
2021-08-14 accel fix at 1000hz sample rate
    [SingleAPM.cpp, SingleAPM.hpp]
2021-09-24 json config splite fix quad 2806 config add APMconfig.json now move to /boot/ json config generator add remove unuse config struct
    [SingleAPM.cpp, SingleAPM.hpp]
2021-09-27 Deinit esc request fix
    [SingleAPM.cpp]
2021-10-23 if logic chains fix
    [SingleAPM.cpp]
2021-11-04 fix valgrind uninit error
    [SingleAPM.hpp]
2021-11-07 complete remove wirintgpi (untest
2021-11-08 pca9685 fix , now usable
    [pca9685.h]
2021-11-08 SPI config channel add
2021-11-08 wiringpi remove link mpu update: fix gyro angle with imu dt
2021-11-12 blackbox predictor 1 fix , predictor 2 supported
    [Blackbox.hpp, blackboxTester.cpp]
2021-11-13 Blackbox tools render pass, Exploer still not work predictor 3 unusable
    [Blackbox.hpp, SingleAPM.cpp, SingleAPM.hpp]
2021-11-14 fix a ',' for blackbox-viewer in header cause nan failed for a parser write with js take tons of time to debug
    [Blackbox.hpp, SingleAPM.cpp]
2021-11-14 blackbox imudt and nav support
2021-11-15 fix dt overclock cause output max or min
    [SingleAPM.cpp]
2021-11-16 Interval config fix, only 1/1,1/2,1/4
    [SingleAPM.cpp, SingleAPM.hpp]
2021-11-18 compass implement complete,still improve nav dt error notice
    [SingleAPM.cpp, SingleAPM.hpp]
2021-11-18 i2cdevice implement improve compass config
2021-11-19 AHRS yaw head support
2021-11-19 DT issues fix,compass improve https://github.com/TSKangetsu/RPiSingleAPM/issues/90
    [SingleAPM.cpp, SingleAPM.hpp]
2021-11-21 MPU fix blackbox dynamic notch add
    [SingleAPM.cpp]
2021-11-23 CP: pitch revert MPU flip support
    [SingleAPM.cpp, SingleAPM.hpp]
2021-12-01 mag input fix, gps add untest gyro raw blackbox add
    [SingleAPM.cpp, SingleAPM.hpp]
2021-12-03 MAG cali failed add
    [SingleAPM.cpp, SingleAPM.hpp]
2021-12-04 fix mag calibration
2021-12-06 calibration fix
2021-12-08 revert GPS X and Y
    [SingleAPM.cpp, SingleAPM.hpp]
2021-12-13 esc driver oneshot i2c addr fix
    [ESCGenerator.hpp]
2021-12-15 gettimeofday issues fix I2C device lock
    [PowerADC.hpp, SingleAPM.cpp, SingleAPM.hpp]
2021-12-22 compass fix compass flip picth revert to roll bug fix compass vetor calibrate support QMC5883 Z revert
    [SingleAPM.cpp]
2021-12-24 MPU real Yaw fix HMC5883L Default
    [SingleAPM.cpp, SingleAPM.hpp]
2022-01-06 fix GPS error issues
    [SingleAPM.cpp]
2022-01-07 GPS hold revert fix , untest
    [SingleAPM.cpp, SingleAPM.hpp]
2022-03-20 single bat voltage add
2022-03-23 position output fix (pitch for accel is y, WTF was I doing?)
    [SingleAPM.cpp]
2022-04-21 cp: important! switch to FlowThread control
2022-04-21 Flow improve
2022-04-22 fix flowthread construtor bug
    [FlowController.hpp]
2022-04-22 flow thread bug fix
    [FlowController.hpp, SingleAPM.cpp]
2022-09-11 fix INA226 I2C handle
    [SingleAPM.cpp, SingleAPM.hpp]
2022-09-19 fix sonar altitude not imp
    [SingleAPM.cpp, SingleAPM.hpp]
2022-09-26 Fix auto takeoff alt reference error
    [SingleAPM.cpp, SingleAPM.hpp]
2022-09-29 fix OPFLow DT x / 0 bug (important fix flowthread time start
    [FlowController.hpp, SingleAPM.cpp]
2022-10-02 flowthread base,add sleep avoid lock before wait fix MSPFlow bug,crc support
    [FlowController.hpp]
2022-10-04 Fix GPS error flag bug
    [SingleAPM.cpp, SingleAPM.hpp]
2022-10-10 flow blackbox add rc fallback. crc problem
    [SingleAPM.cpp]
2022-10-11 fix rc blackbox error fix config calibration
    [SingleAPM.cpp]
2022-10-13 RC update, flow not fix, don't use
2022-10-18 acc Notch add flow crc fix
    [SingleAPM.cpp]
2022-10-26 check point!!! nav XY fallback https://github.com/TSKangetsu/RPiSingleAPM/issues/46
    [SingleAPM.cpp, SingleAPM.hpp]
2022-11-19 fix ioctl for musl
    [PowerADC.hpp, pca9685.h]
2023-03-13 pwm support, user implement example add
2023-09-01 full crsf support fixme: need read design rc read logic
    [SingleAPM.cpp, SingleAPM.hpp]
2023-09-05 improve flow
2023-09-17 ADS111x support,flow testing dont use
2023-09-18 nav XY fix, flow reversed
    [SingleAPM.cpp, SingleAPM.hpp]
2023-10-21 telemetry GPS supported test,remote debug fix
    [SingleAPM.cpp, SingleAPM.hpp]
2023-10-21 fix telemetry rate, arm Wait
    [SingleAPM.cpp, SingleAPM.hpp]
2023-11-12 IMUdt fliter add, yaw blackbox improve
2024-05-07 fix for openwrt gcc_pic https://github.com/openwrt/openwrt/issues/6710
    [SingleAPM.cpp]
2024-05-10 baro bmp280 add mpu fix
    [SingleAPM.cpp, SingleAPM.hpp]
2024-05-25 nano pi air hat adc change
2024-05-25 upgrade for MPU driver TODO: add auto MPU device detection
2024-07-19 jsongener fix, remove unuse ekf
    [SingleAPM.hpp]
